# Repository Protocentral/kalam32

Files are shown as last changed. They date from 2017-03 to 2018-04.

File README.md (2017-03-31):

# ProtoCentral Kalam32-Dev ESP32 Wi-Fi and Bluetooth IoT platform
-------------------

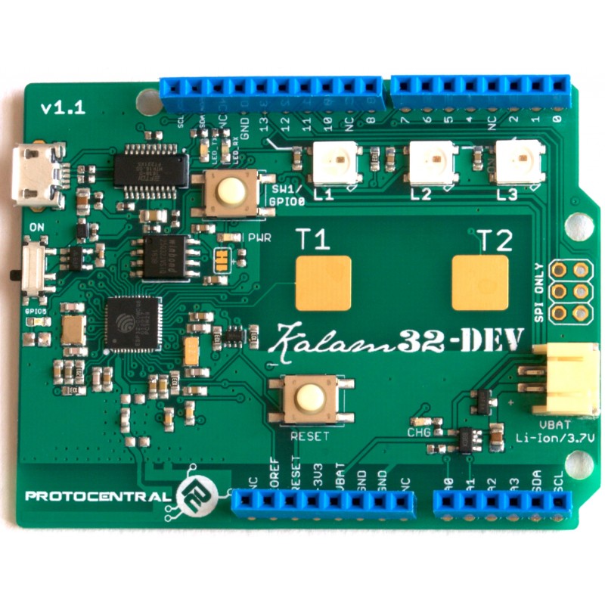
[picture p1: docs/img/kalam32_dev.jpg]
Kalam32-Dev
[!
Dont have it yet? But one here: ProtoCentral Kalam32-Dev ESP32 Wi-Fi and Bluetooth IoT platform](https://www.protocentral.com/kalam-iot/1156-protocentral-kalam32-dev-esp32-wi-fi-and-bluetooth-iot-platform.html)

Meet the Espressif ESP32, a much-awaited sequel of the very popular ESP8266 SoC. This time around Espressif has given it a ton of integrated feature-rich peripherals. The CPU(s) is also upgraded with two individual cores from Tensilica, each running at up to 240 MHz. Two because one takes care of the Wi-Fi and Bluetooth stacks' computational requirements and the other one dedicated for the application.

This is just a lot of power waiting to be unleashed and still works on very low power for IoT applications. We are very excited with the capability of this chip and waiting to find more applications for it.

At the time of writing this document, the support for ESP32 in Arduino is still kind of patchy, however Espressif has an excellent development toolchain based on the Xtensa toolchain for Tensilica controllers. We love using Epressif's ESP-IDF toolchain and framework, it includes a great set of libraries. It works on Windows, MACOS and Linux. We use it on Ubuntu and it works like a charm.

Note: This product is still undergoing complete software testing for the various capabilities. Watch this page for more updates as we keep adding features in software for this.

Note: The Arduino core for ESP32 is still under development, so with the current state of the software, this board may not be a drop-in replacement for an Arduino. This feature should be available soon though.

##Features:

* On-board ESP32 System-On-Chip (SoC) featuring:
* Two Tensilica LX6 microcontroller cores running at 240 MHz, with 520 KB RAM !!
* Integrated Wi-Fi controller (802.11 b/g/n/i) up to 150 Mbps
* Integrated Dual-mode Bluetooth 4.2 controller ("classic" and Bluetooth low * energy (BLE) support)
* 12-bit SAR 12-channel ADC
* 8-bit, 2-channel DAC
* Capacitive touch sensor interface
* LED PWM controller
* CAN 2.0 controller
* Integrated temperature sensor
* Integrated Hall-effect sensor 
* Operating temperature range: -40 C to +125 C
* 4 MB on-board FLASH memory
* On-board 2.4 GHz PCB trace antenna for Wi-Fi/Bluetooth
* On-board FTDI FT231X USB-UART converter
* Operation from single Li-Poly battery with on-board charger and regulator
* 2x capacitive touch switches
* 3x WS2812B addressable RGB LEDs
* Arduino Uno compatible form-factor for addition of shields

Repository Contents
-------------------
* **/hardware** - All Eagle design files (.brd, .sch)
* **/docs** - Additional Documentation

License Information
-------------------
This product is open source!

Please use, reuse, and modify these files as you see fit. Please maintain attribution to Protocentral and release anything derivative under the same license.

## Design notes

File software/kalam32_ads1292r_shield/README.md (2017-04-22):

ADS1292R Example Code for Kalam32
====================

This project is code for the [ProtoCentral Kalam32-DEV IoT development board](https://www.protocentral.com/kalam-iot/1156-protocentral-kalam32-dev-esp32-wi-fi-and-bluetooth-iot-platform.html) working as a TCP server and interfacing with the [ADS1292R ECG/Respiration Shield](https://www.protocentral.com/biomedical-shields/818-ads1292r-ecgrespiration-shield-v2.html). This demonstrates the use of the Kalam32 for simple connected applications.

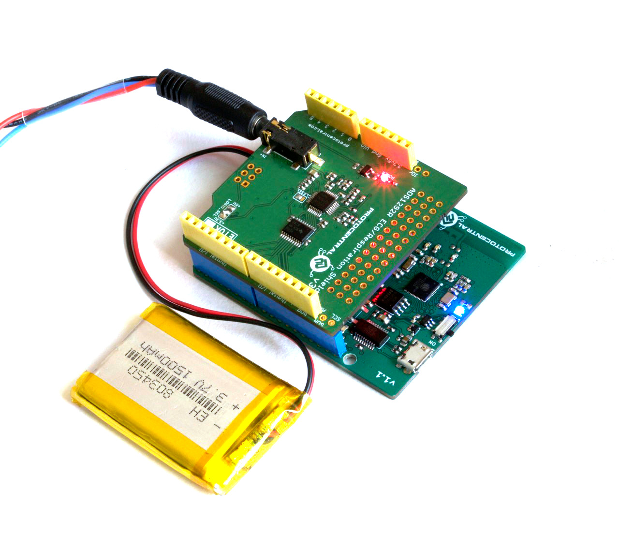
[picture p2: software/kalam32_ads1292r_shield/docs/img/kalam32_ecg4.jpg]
ProtoCentral Kalam32 with the ADS1292R shield


This code works only with the [Espressif ESP-IoT Development Framework (ESP-IDF)](https://github.com/espressif/esp-idf) and its associated toolchain.

For compilation and execution instructions, please refer to [Espressif's guide to get started with ESP-IDF](http://esp-idf.readthedocs.io).

License Information
===================

This product is open source! Both, our hardware and software are open source and licensed under the following licenses:

Hardware
---------

**All hardware is released under [Creative Commons Share-alike 4.0 International](http://creativecommons.org/licenses/by-sa/4.0/).**


You are free to:

* Share — copy and redistribute the material in any medium or format
* Adapt — remix, transform, and build upon the material for any purpose, even commercially.
The licensor cannot revoke these freedoms as long as you follow the license terms.

Under the following terms:

* Attribution — You must give appropriate credit, provide a link to the license, and indicate if changes were made. You may do so in any reasonable manner, but not in any way that suggests the licensor endorses you or your use.
* ShareAlike — If you remix, transform, or build upon the material, you must distribute your contributions under the same license as the original.

Software
--------

**All software is released under the MIT License(http://opensource.org/licenses/MIT).**

THE SOFTWARE IS PROVIDED "AS IS", WITHOUT WARRANTY OF ANY KIND, EXPRESS OR IMPLIED, INCLUDING BUT NOT LIMITED TO THE WARRANTIES OF MERCHANTABILITY, FITNESS FOR A PARTICULAR PURPOSE AND NONINFRINGEMENT. IN NO EVENT SHALL THE AUTHORS OR COPYRIGHT HOLDERS BE LIABLE FOR ANY CLAIM, DAMAGES OR OTHER LIABILITY, WHETHER IN AN ACTION OF CONTRACT, TORT OR OTHERWISE, ARISING FROM, OUT OF OR IN CONNECTION WITH THE SOFTWARE OR THE USE OR OTHER DEALINGS IN THE SOFTWARE.

Please check [*LICENSE.md*](LICENSE.md) for detailed license descriptions.

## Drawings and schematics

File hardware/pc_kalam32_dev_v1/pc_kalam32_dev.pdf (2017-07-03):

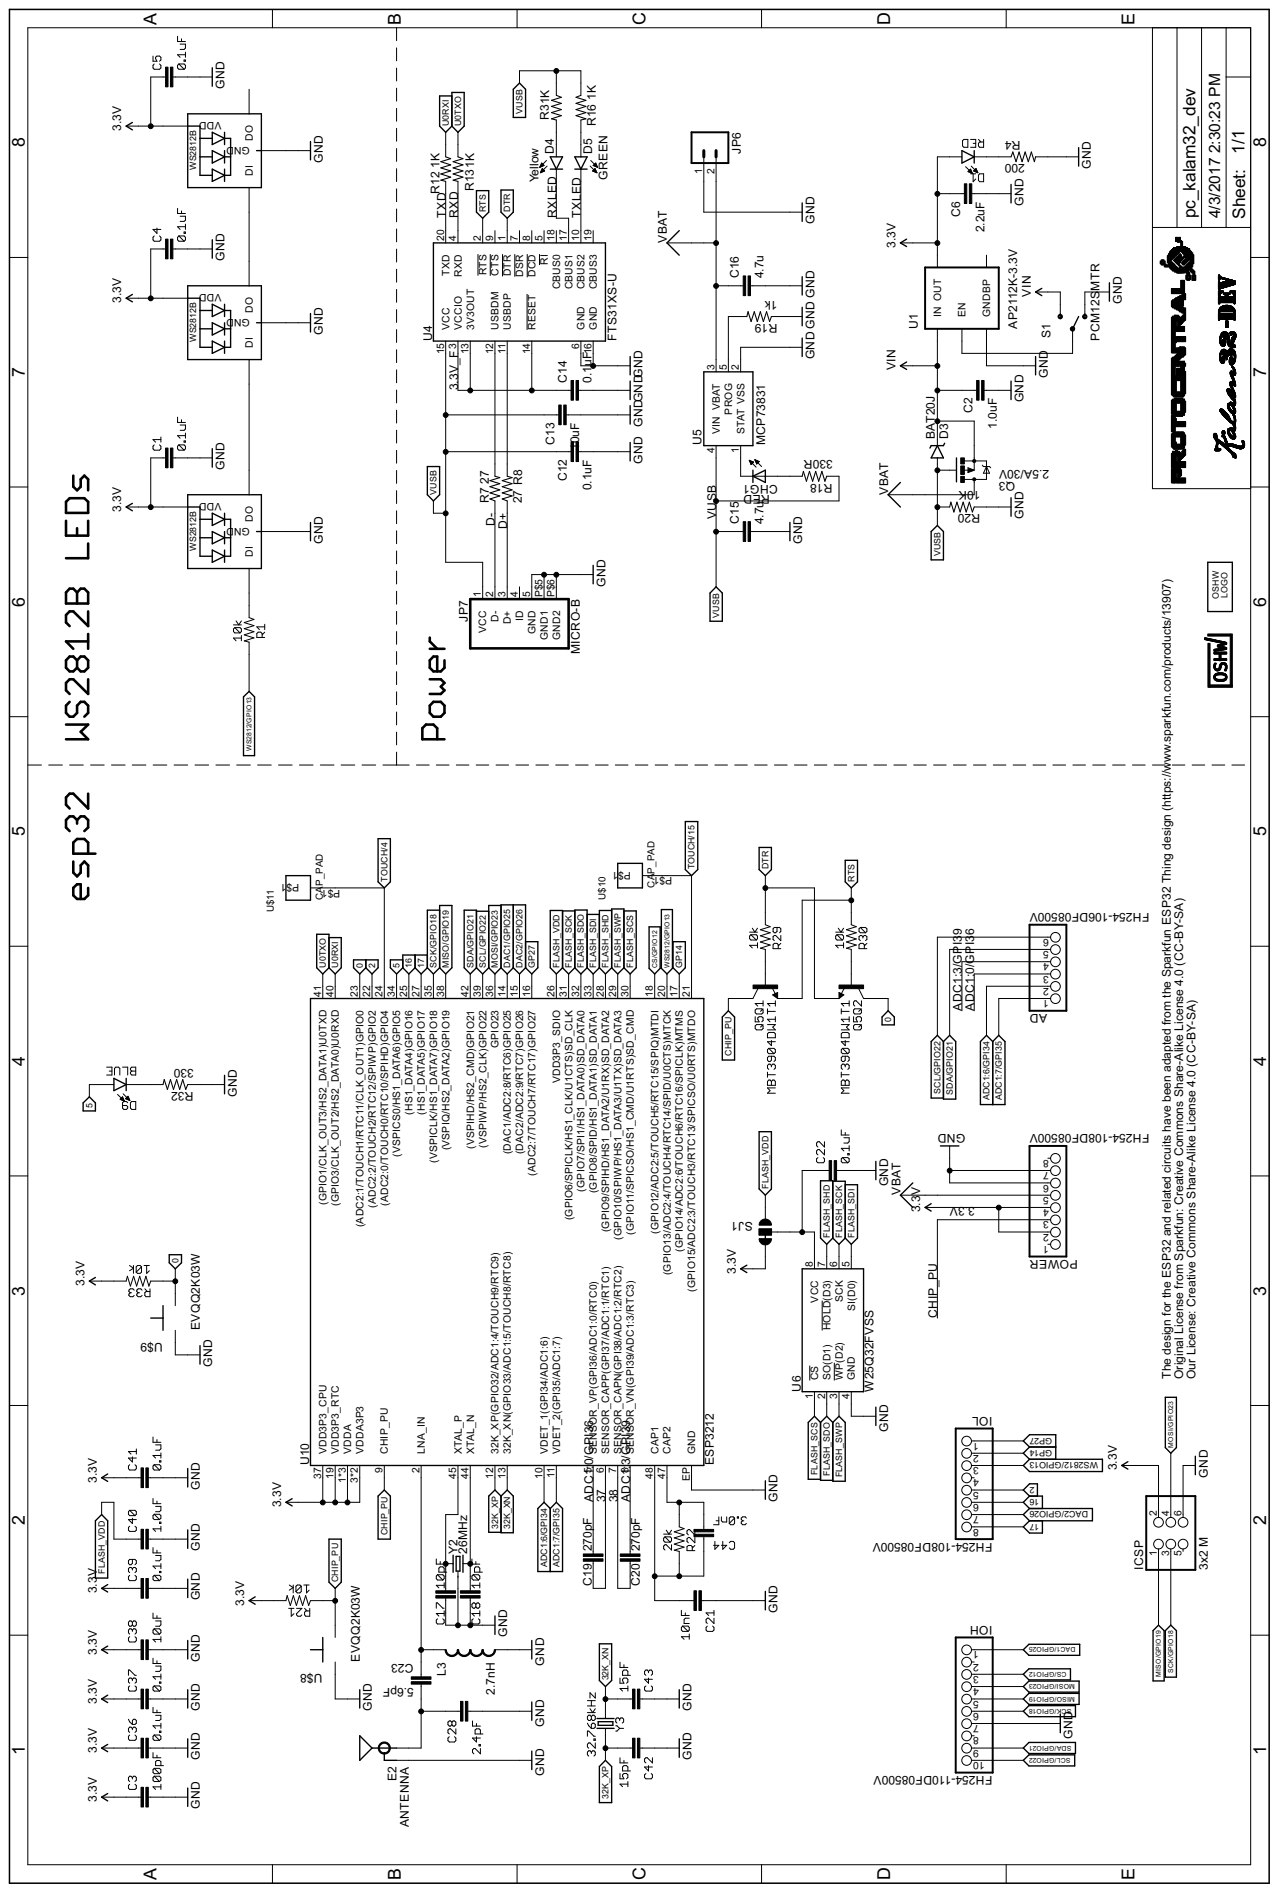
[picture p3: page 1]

0.1uF GND GND GND GND

The design for the ESP32 and related circuits have been adapted from the Sparkfun ESP32 Thing design (https:/ www.sparkfun.com/products/13907) Original License from Sparkfun: Creative Commons Share-Alike License 4.0 (CC-BY-SA) Our License: Creative Commons Share-Alike License 4.0 (CC-BY-SA)

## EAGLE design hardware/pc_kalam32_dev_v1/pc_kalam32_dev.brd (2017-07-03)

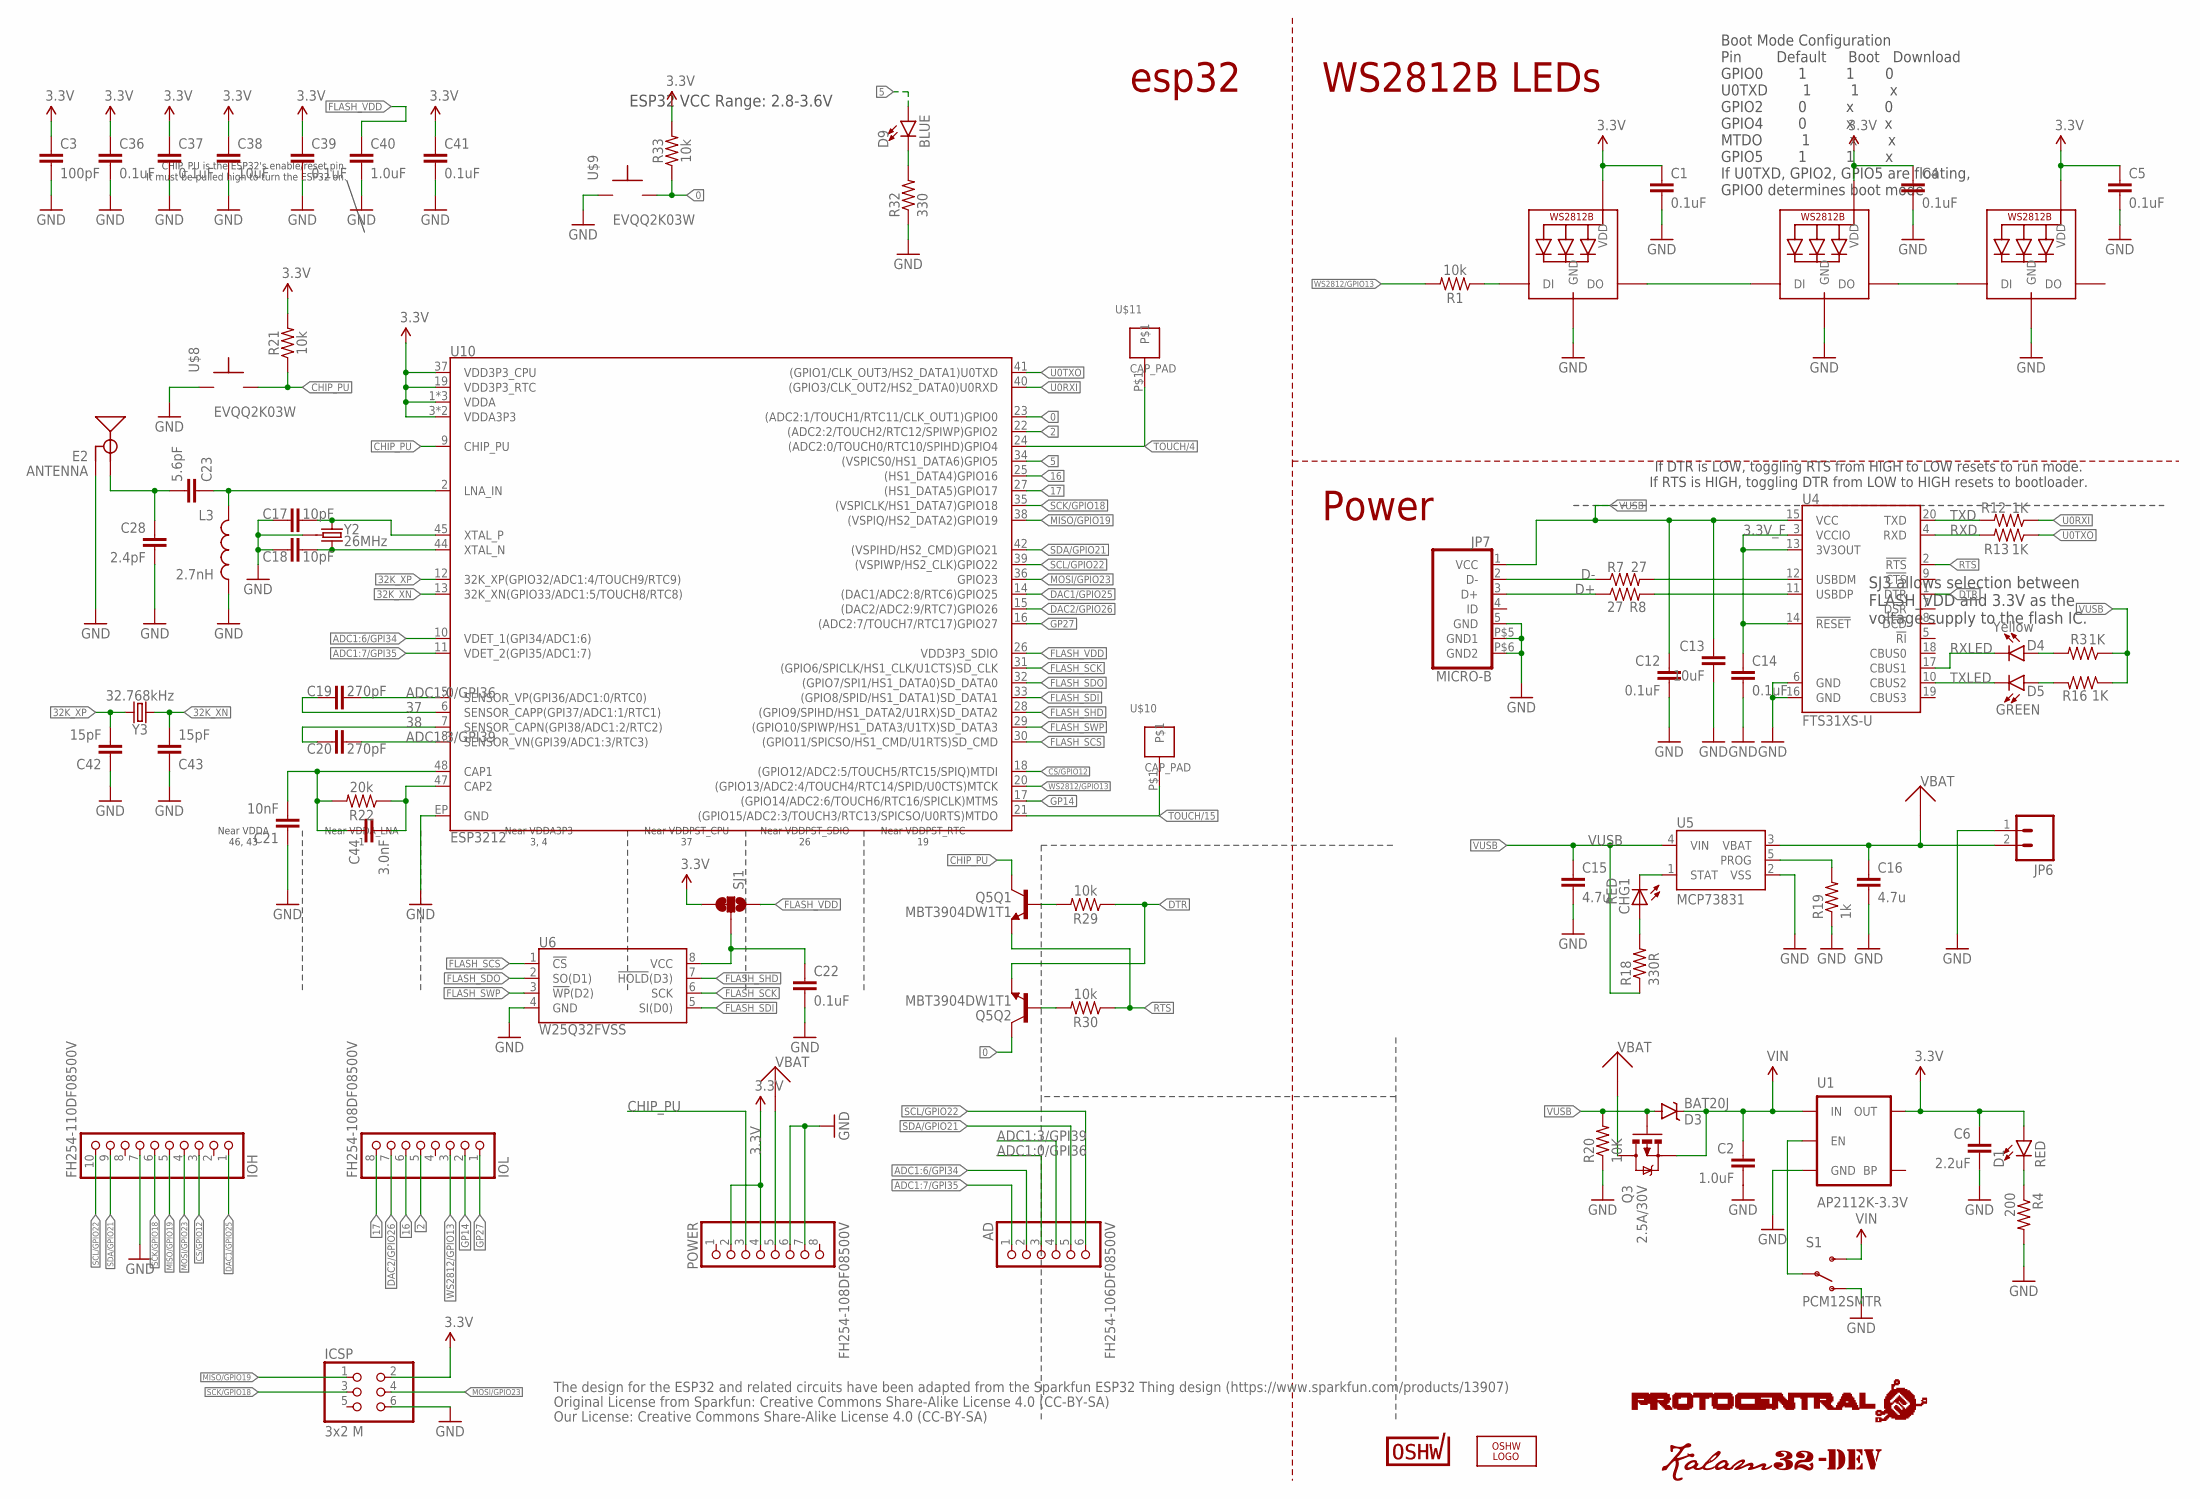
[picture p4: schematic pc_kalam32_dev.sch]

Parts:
AD: FH254-106DF08500V; 1X06
C1, C4, C5, C22, C36, C37, C39, C41: 0.1uF; 0603
C2: 1.0uF; C0402
C3: 100pF; 0603
C6: 2.2uF; 0603-CAP@1
C12, C14: 0.1uF; C0402
C13: 10uF; C0805
C15, C16: 4.7u; C0805
C17, C18: 10pF; 0603
C19, C20: 270pF; 0603
C21: 10nF; 0603
C23: 5.6pF; 0603
C28: 2.4pF; 0603
C38: 10uF; 0603
C40: 1.0uF; 0603
C42, C43: 15pF; 0603
C44: 3.0nF; 0603
CHG1: RED; CHIPLED_0603
D1: RED; LED-0603
D3: BAT20J; SOD-323
D4: Yellow; LED-0603
D5: GREEN; LED-0603@1
D9: BLUE; LED-0603
E2: ANTENNA; TRACE_ANTENNA_2.4GHZ_25.7MM_TUNED
ICSP: 3x2 M; 2X03
IOH: FH254-110DF08500V; 1X10
IOL: FH254-108DF08500V; 1X08
JP6: M02-JST-2MM-SMT; JST-2-SMD
JP7: MICRO-B
L3: 2.7nH; 0603
LED1, LED2, LED3: WS2812B5050; WS2812B
LOGO2: OSHW_LOGO_FILLX0200-NT; OSHW_FILLX200_NOTEXT
POWER: FH254-108DF08500V; 1X08
Q3: 2.5A/30V; SOT23-3
Q5: MBT3904DW1T1; SC70-6
R1, R21, R29, R30, R33: 10k; 0603
R3, R12, R13, R16: 1K; R0402
R4: 200; R0402
R7, R8: 27; R0402
R18: 330R; R0402
R19: 1k; R0402
R20: 10K; R0402
R22: 20k; 0603
R32: 330; R0805
S1: PCM12SMTR; SWITCH-SPST-SMD-A
SJ1: JUMPER-PAD-3-2OF3_NC_BY_TRACE_SMALL; PAD-JUMPER-3-2OF3_NC_BY_TRACE_YES_SILK_FULL_BOX
U1: AP2112K-3.3V; SOT23-5
U4: FTS31XS-U; SSOP20_L
U5: MCP73831; SOT23-5
U6: W25Q32FVSS; SOIC-8
U10: ESP3212; QFN48-0.4MM
U$5: CERT-MEDIUM; CERT-MED-SILK
U$8, U$9: EVQQ2K03W; EVQQ2
U$10, U$11: CAP_PAD
U$12: KALAM32-DEV
U$13: PROTY_LOGO_WITH_TEXT; PROTY_WITH_TEXT
Y2: 26MHz; CRYSTAL-SMD-3.2X2.5
Y3: 32.768kHz; CRYSTAL-SMD-3.2X1.5MM

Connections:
0: Q5.6 (C), R33.1, U10.23 ((ADC2:1/TOUCH1/RTC11/CLK_OUT1)GPIO0), U$9.P$3
2: IOL.5, U10.22 ((ADC2:2/TOUCH2/RTC12/SPIWP)GPIO2)
3.3V: C1.1, C3.1, C4.1, C5.1, C6.1, C36.1, C37.1, C38.1, C39.1, C41.1, D1.A, ICSP.2, LED1.1-VDD (VDD), LED2.1-VDD (VDD), LED3.1-VDD (VDD), POWER.2, POWER.4, R21.2, R33.2, SJ1.3, U1.5 (OUT), U10.1 (VDDA), U10.3 (VDDA3P3), U10.4 (VDDA3P3), U10.19 (VDD3P3_RTC), U10.37 (VDD3P3_CPU), U10.43 (VDDA), U10.46 (VDDA)
3.3V_F: C14.1, U4.3 (VCCIO), U4.13 (3V3OUT), U4.14 (!RESET)
5: D9.A, U10.34 ((VSPICS0/HS1_DATA6)GPIO5)
16: IOL.6, U10.25 ((HS1_DATA4)GPIO16)
17: IOL.8, U10.27 ((HS1_DATA5)GPIO17)
32K_XN: C43.2, U10.13 (32K_XN(GPIO33/ADC1:5/TOUCH8/RTC8)), Y3.P$2 (2)
32K_XP: C42.2, U10.12 (32K_XP(GPIO32/ADC1:4/TOUCH9/RTC9)), Y3.P$1 (1)
37: C19.1, U10.6 (SENSOR_CAPP(GPI37/ADC1:1/RTC1))
38: C20.1, U10.7 (SENSOR_CAPN(GPI38/ADC1:2/RTC2))
ADC1:0/GPI36: AD.3, C19.2, U10.5 (SENSOR_VP(GPI36/ADC1:0/RTC0))
ADC1:3/GPI39: AD.4, C20.2, U10.8 (SENSOR_VN(GPI39/ADC1:3/RTC3))
ADC1:6/GPI34: AD.2, U10.10 (VDET_1(GPI34/ADC1:6))
ADC1:7/GPI35: AD.1, U10.11 (VDET_2(GPI35/ADC1:7))
CAP_10N: C21.2, C44.1, R22.2, U10.48 (CAP1)
CHIP_PU: POWER.3, Q5.3 (C), R21.1, U10.9 (CHIP_PU), U$8.P$3
CS/GPIO12: IOH.3, U10.18 ((GPIO12/ADC2:5/TOUCH5/RTC15/SPIQ)MTDI)
D+: JP7.3 (D+), R8.1
D-: JP7.2 (D-), R7.1
DAC1/GPIO25: IOH.1, U10.14 ((DAC1/ADC2:8/RTC6)GPIO25)
DAC2/GPIO26: IOL.7, U10.15 ((DAC2/ADC2:9/RTC7)GPIO26)
DTR: Q5.1 (E), R29.1, U4.1 (!DTR)
FLASH_SCK: U6.6 (SCK), U10.31 ((GPIO6/SPICLK/HS1_CLK/U1CTS)SD_CLK)
FLASH_SCS: U6.1 (!CS!), U10.30 ((GPIO11/SPICSO/HS1_CMD/U1RTS)SD_CMD)
FLASH_SDI: U6.5 (SI(D0)), U10.33 ((GPIO8/SPID/HS1_DATA1)SD_DATA1)
FLASH_SDO: U6.2 (SO(D1)), U10.32 ((GPIO7/SPI1/HS1_DATA0)SD_DATA0)
FLASH_SHD: U6.7 (!HOLD!(D3)), U10.28 ((GPIO9/SPIHD/HS1_DATA2/U1RX)SD_DATA2)
FLASH_SWP: U6.3 (!WP!(D2)), U10.29 ((GPIO10/SPIWP/HS1_DATA3/U1TX)SD_DATA3)
FLASH_VDD: C40.1, SJ1.1, U10.26 (VDD3P3_SDIO)
GND: C1.2, C2.2, C3.2, C4.2, C5.2, C6.2, C12.2, C13.2, C14.2, C15.2, C16.2, C17.1, C18.1, C21.1, C22.2, C28.2, C36.2, C37.2, C38.2, C39.2, C40.2, C41.2, C42.1, C43.1, E2.GND, E2.GND2 (GND), ICSP.6, IOH.7, JP6.1, JP7.5 (GND), JP7.P$5 (GND1), JP7.P$6 (GND2), L3.2, LED1.3-GND (GND), LED2.3-GND (GND), LED3.3-GND (GND), POWER.6, POWER.7, R4.2, R19.1, R20.1, R32.1, S1.1 (O), U1.2 (GND), U4.6 (GND), U4.16 (GND), U5.2 (VSS), U6.4 (GND), U10.EP (GND), U$8.P$1, U$9.P$1, Y2.2 (GND), Y2.4 (GND)
GP14: IOL.2, U10.17 ((GPIO14/ADC2:6/TOUCH6/RTC16/SPICLK)MTMS)
GP27: IOL.1, U10.16 ((ADC2:7/TOUCH7/RTC17)GPIO27)
LNA_IN: C23.1, L3.1, U10.2 (LNA_IN)
MISO/GPIO19: ICSP.1, IOH.5, U10.38 ((VSPIQ/HS2_DATA2)GPIO19)
MOSI/GPIO23: ICSP.4, IOH.4, U10.36 (GPIO23)
unnamed: LED1.2-DOUT (DO), LED2.4-DIN (DI)
unnamed: LED2.2-DOUT (DO), LED3.4-DIN (DI)
unnamed: LED1.4-DIN (DI), R1.1
unnamed: D5.A, R16.2
unnamed: R7.2, U4.12 (USBDM)
unnamed: D4.A, R3.2
unnamed: R8.2, U4.11 (USBDP)
unnamed: D1.C, R4.1
unnamed: CHG1.C, U5.1 (STAT)
unnamed: S1.2, U1.3 (EN)
unnamed: CHG1.A, R18.2
unnamed: C22.1, SJ1.2, U6.8 (VCC)
unnamed: R19.2, U5.5 (PROG)
unnamed: Q5.5 (B), R29.2
unnamed: Q5.2 (B), R30.2
unnamed: C17.2, U10.45 (XTAL_P), Y2.1
unnamed: C18.2, U10.44 (XTAL_N), Y2.3 (2)
unnamed: D9.C, R32.2
unnamed: C44.2, R22.1, U10.47 (CAP2)
RTS: Q5.4 (E), R30.1, U4.2 (!RTS)
RXD: R13.2, U4.4 (RXD)
RXLED: D4.C, U4.17 (CBUS1)
SCK/GPIO18: ICSP.3, IOH.6, U10.35 ((VSPICLK/HS1_DATA7)GPIO18)
SCL/GPIO22: AD.6, IOH.10, U10.39 ((VSPIWP/HS2_CLK)GPIO22)
SDA/GPIO21: AD.5, IOH.9, U10.42 ((VSPIHD/HS2_CMD)GPIO21)
TOUCH/4: U10.24 ((ADC2:0/TOUCH0/RTC10/SPIHD)GPIO4), U$11.P$1
TOUCH/15: U10.21 ((GPIO15/ADC2:3/TOUCH3/RTC13/SPICSO/U0RT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), U$10.P$1
TRACE_ANT1: C23.2, C28.1, E2.ANT (SIGNAL)
TXD: R12.2, U4.20 (TXD)
TXLED: D5.C, U4.10 (CBUS2)
U0RXI: R12.1, U10.40 ((GPIO3/CLK_OUT2/HS2_DATA0)U0RXD)
U0TXO: R13.1, U10.41 ((GPIO1/CLK_OUT3/HS2_DATA1)U0TXD)
VBAT: C16.1, JP6.2, POWER.5, Q3.3 (D), U5.3 (VBAT)
VIN: C2.1, D3.C, Q3.2 (S), S1.3 (S), U1.1 (IN)
VUSB: C12.1, C13.1, C15.1, D3.A, JP7.1 (VCC), Q3.1 (G), R3.1, R16.1, R18.1, R20.2, U4.15 (VCC), U5.4 (VIN)
WS2812/GPIO13: IOL.3, R1.2, U10.20 ((GPIO13/ADC2:4/TOUCH4/RTC14/SPID/U0CTS)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)

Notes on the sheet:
Boot Mode Configuration Pin Default Boot Download GPIO0 1 1 0 U0TXD 1 1 x GPIO2 0 x 0 GPIO4 0 x x MTDO 1 x x GPIO5 1 1 x If U0TXD, GPIO2, GPIO5 are floating, GPIO0 determines boot mode
Near VDDA 46, 43
Near VDDA_LNA 1
Near VDDA3P3 3, 4
Near VDDPST_CPU 37
Near VDDPST_SDIO 26
Near VDDPST_RTC 19
ESP32 VCC Range: 2.8-3.6V
SJ3 allows selection between FLASH_VDD and 3.3V as the voltage supply to the flash IC.
If DTR is LOW, toggling RTS from HIGH to LOW resets to run mode. If RTS is HIGH, toggling DTR from LOW to HIGH resets to bootloader.
CHIP_PU is the ESP32's enable/reset pin. It must be pulled high to turn the ESP32 on.
esp32
The design for the ESP32 and related circuits have been adapted from the Sparkfun ESP32 Thing design (https://www.sparkfun.com/products/13907)
Original License from Sparkfun: Creative Commons Share-Alike License 4.0 (CC-BY-SA)
Our License: Creative Commons Share-Alike License 4.0 (CC-BY-SA)
WS2812B LEDs
Power

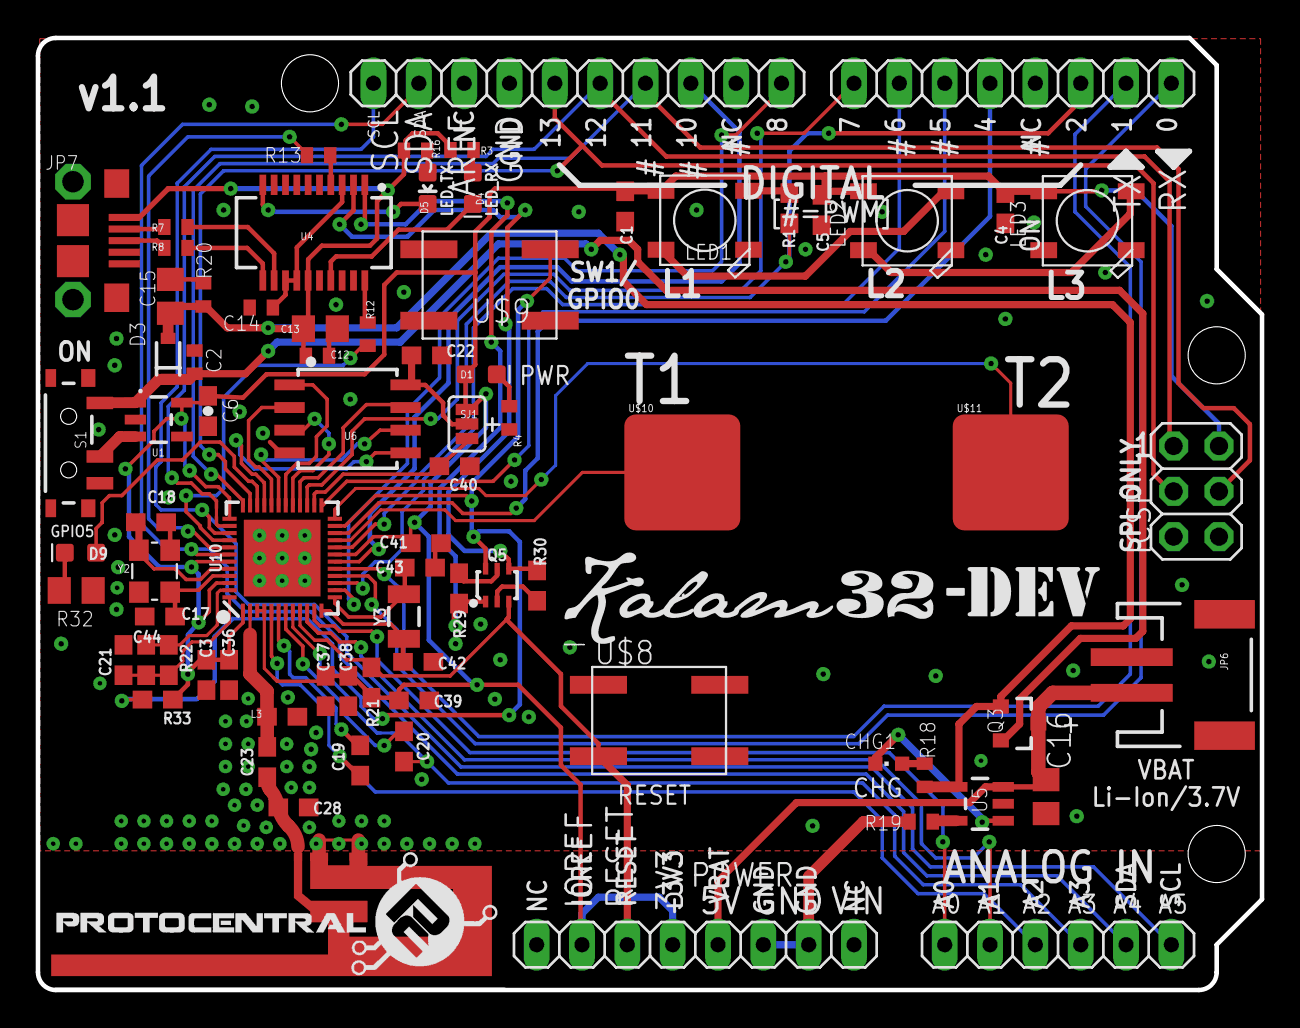
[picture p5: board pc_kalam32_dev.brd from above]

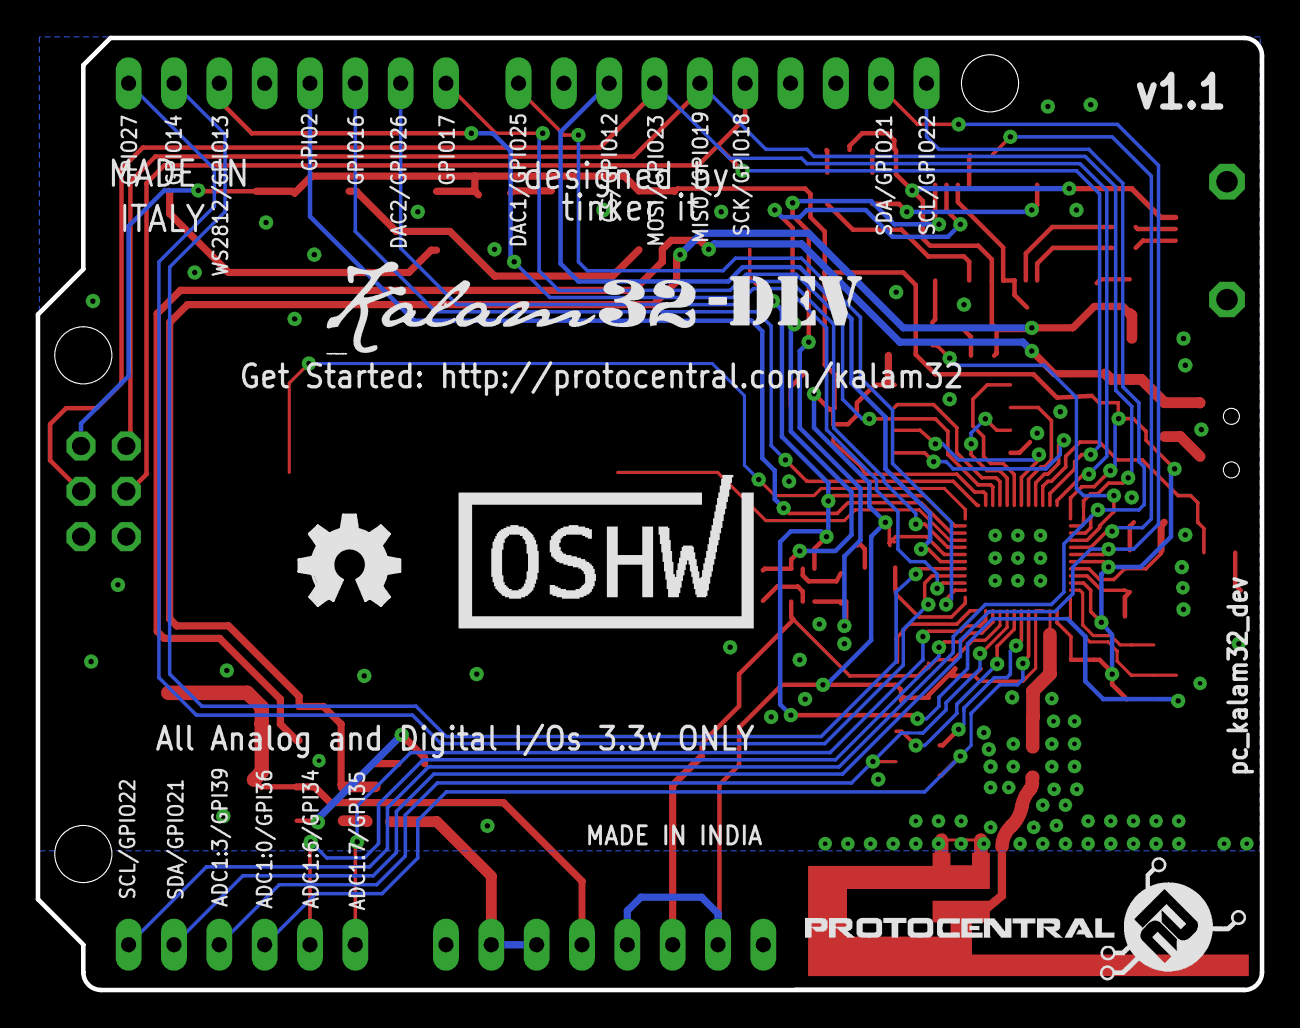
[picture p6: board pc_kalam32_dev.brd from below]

Board: 4 copper layers, 68.6 x 53.3 mm, 84 parts (4 on the bottom side), 72 nets.

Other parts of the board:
U$1: KALAM32-DEV
U$2: PROTY_LOGO_WITH_TEXT; PROTY_WITH_TEXT

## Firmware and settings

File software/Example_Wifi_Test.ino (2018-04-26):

#include <WiFi.h>

// WiFi network name and password:
const char * networkName = "YOUR NETWORK NAME";
const char * networkPswd = "YOUR PASSWORD";

// Internet domain to request from:
const char * hostDomain = "example.com";
const int hostPort = 80;

const int BUTTON_PIN = 0;
const int LED_PIN = 5;

void setup()
{
  // Initilize hardware:
  Serial.begin(115200);
  pinMode(BUTTON_PIN, INPUT_PULLUP);
  pinMode(LED_PIN, OUTPUT);

  // Connect to the WiFi network (see function below loop)
  connectToWiFi(networkName, networkPswd);

  digitalWrite(LED_PIN, LOW); // LED off
  Serial.print("Press button 0 to connect to ");
  Serial.println(hostDomain);
}

void loop()
{
  if (digitalRead(BUTTON_PIN) == LOW)
  { // Check if button has been pressed
    while (digitalRead(BUTTON_PIN) == LOW)
      ; // Wait for button to be released

    digitalWrite(LED_PIN, HIGH); // Turn on LED
    requestURL(hostDomain, hostPort); // Connect to server
    digitalWrite(LED_PIN, LOW); // Turn off LED
  }
}

void connectToWiFi(const char * ssid, const char * pwd)
{
  int ledState = 0;

  printLine();
  Serial.println("Connecting to WiFi network: " + String(ssid));

  WiFi.begin(ssid, pwd);

  while (WiFi.status() != WL_CONNECTED) 
  {
    // Blink LED while we're connecting:
    digitalWrite(LED_PIN, ledState);
    ledState = (ledState + 1) % 2; // Flip ledState
    delay(500);
    Serial.print(".");
  }

  Serial.println();
  Serial.println("WiFi connected!");
  Serial.print("IP address: ");
  Serial.println(WiFi.localIP());
}

void requestURL(const char * host, uint8_t port)
{
  printLine();
  Serial.println("Connecting to domain: " + String(host));

  // Use WiFiClient class to create TCP connections
  WiFiClient client;
  if (!client.connect(host, port))
  {
    Serial.println("connection failed");
    return;
  }
  Serial.println("Connected!");
  printLine();

  // This will send the request to the server
  client.print((String)"GET / HTTP/1.1\r\n" +
               "Host: " + String(host) + "\r\n" +
               "Connection: close\r\n\r\n");
  unsigned long timeout = millis();
  while (client.available() == 0) 
  {
    if (millis() - timeout > 5000) 
    {
      Serial.println(">>> Client Timeout !");
      client.stop();
      return;
    }
  }

  // Read all the lines of the reply from server and print them to Serial
  while (client.available()) 
  {
    String line = client.readStringUntil('\r');
    Serial.print(line);
  }

  Serial.println();
  Serial.println("closing connection");
  client.stop();
}

void printLine()
{
  Serial.println();
  for (int i=0; i<30; i++)
    Serial.print("-");
  Serial.println();
}

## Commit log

2017-03-31 Updated hardware files
    [pc_kalam32_dev.brd, pc_kalam32_dev.sch]
2017-04-01 Updated schematics
    [pc_kalam32_dev.brd, pc_kalam32_dev.sch]
2017-07-03 added design file for v1.1
    [pc_kalam32_dev.brd, pc_kalam32_dev.sch]

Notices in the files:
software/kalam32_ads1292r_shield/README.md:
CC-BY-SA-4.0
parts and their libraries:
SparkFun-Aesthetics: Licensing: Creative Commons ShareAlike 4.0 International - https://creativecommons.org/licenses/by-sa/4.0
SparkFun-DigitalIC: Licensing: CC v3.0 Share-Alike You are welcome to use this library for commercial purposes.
